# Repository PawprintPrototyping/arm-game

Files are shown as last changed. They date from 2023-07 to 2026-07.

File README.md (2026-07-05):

# opensauce23
Code, design files, etc for the coolest robot game at OpenSauce 2023 (and beyond!)

# MQTT System Architecture

The arm-game uses message passing via MQTT topics to drive each gameplay component.  Here's a state diagram showing how each topic drives the gameplay state:

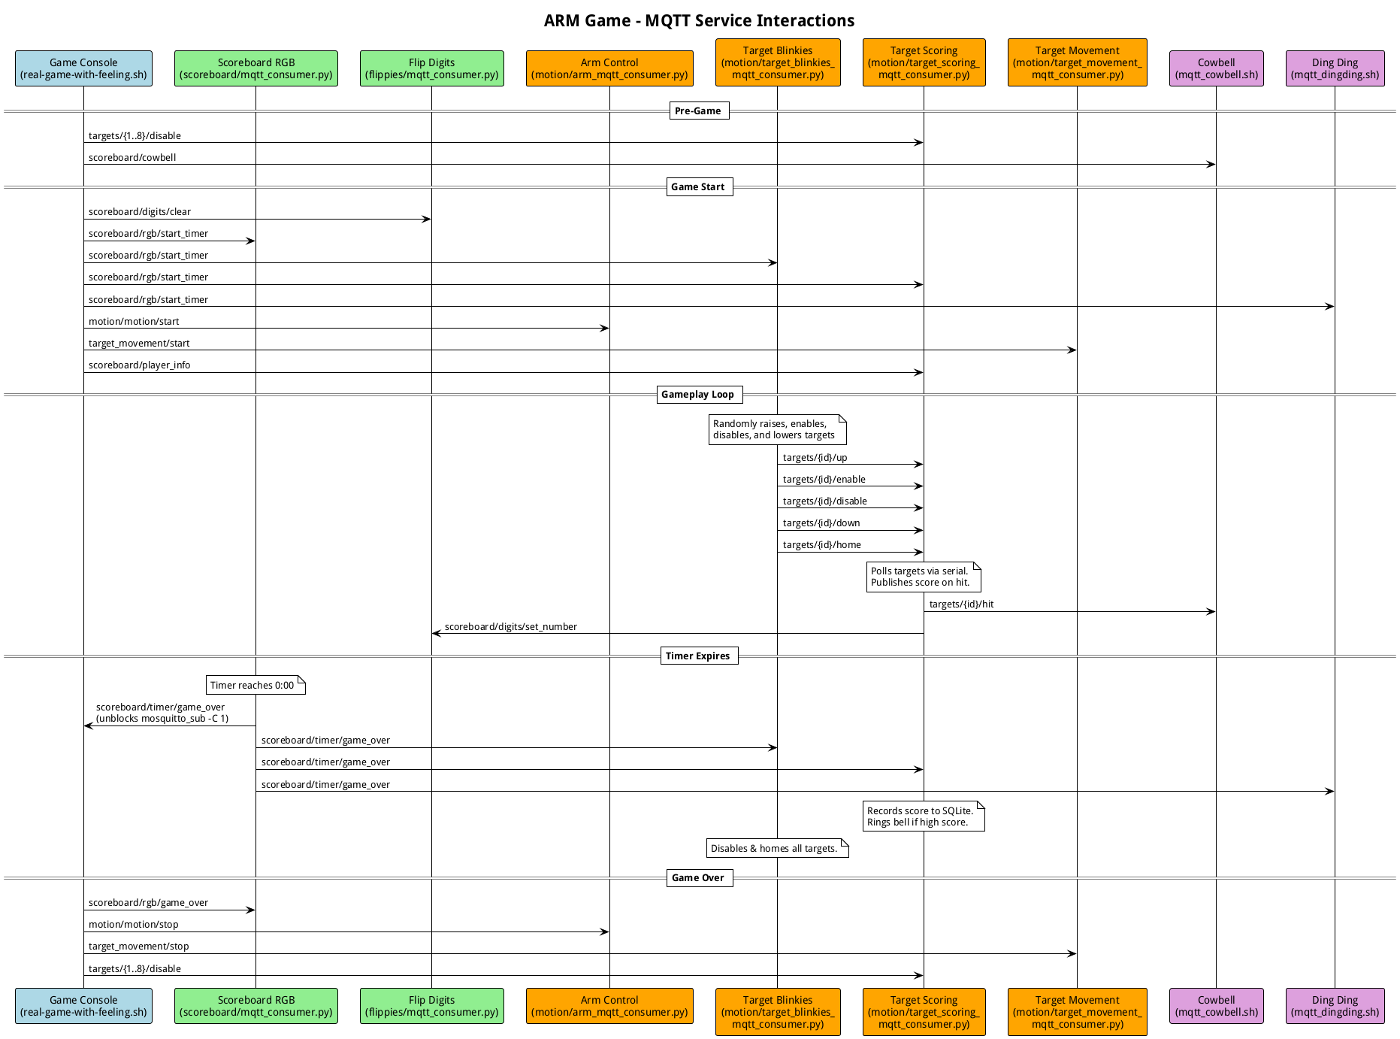
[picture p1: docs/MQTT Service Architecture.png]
MQTT Topic Architecture


Another overview of how each topic queue and component interacts:

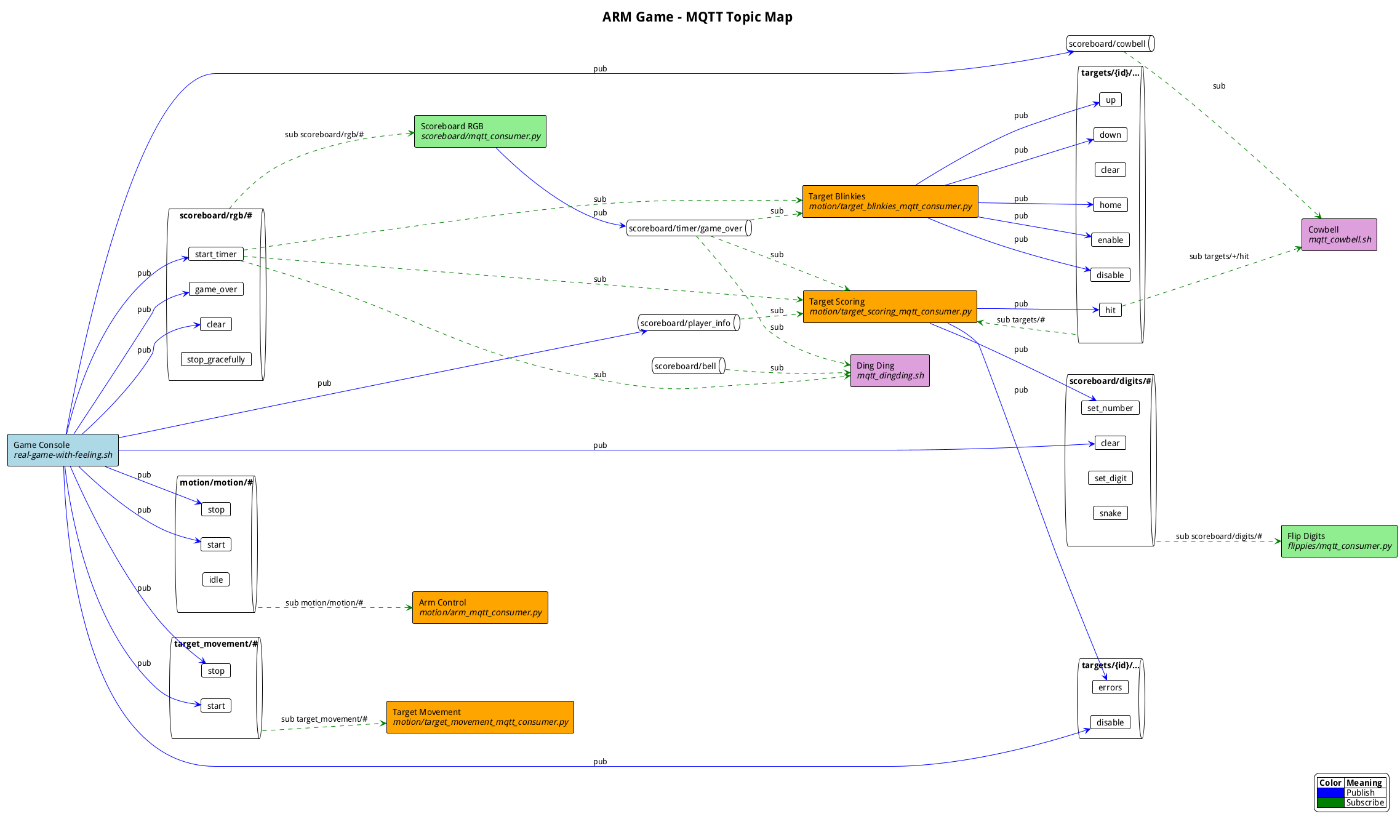
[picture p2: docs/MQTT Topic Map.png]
MQTT Topic Map


Detailed MQTT Topic API documentation can be found in [the docs folder](https://github.com/PawprintPrototyping/arm-game/tree/main/docs).

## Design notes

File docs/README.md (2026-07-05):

# MQTT API documentation

* [Flip Digits API](https://github.com/PawprintPrototyping/arm-game/tree/main/docs/flippies_api.md) - Flip digit scoreboard topics (/scoreboard/digits/...)
* [RGB Scoreboard API](https://github.com/PawprintPrototyping/arm-game/tree/main/docs/scoreboard_api.md) — RGB matrix display topics (/scoreboard/rgb/...)
* [Arm Motion API](https://github.com/PawprintPrototyping/arm-game/tree/main/docs/arm_motion_api.md) — robot arm control (/motion/motion/...)
* [Target Blinkies API](https://github.com/PawprintPrototyping/arm-game/tree/main/target_blinkies_api.md) — target lighty-uppy sequencer (subscribes to timer events, publishes target commands)
* [Target Movement API](https://github.com/PawprintPrototyping/arm-game/tree/main/docs/target_movement_api.md) — stepper motor platform (/target_movement/...)
* [Target Scoring API](https://github.com/PawprintPrototyping/arm-game/tree/main/docs/target_scoring_api.md) — hit detection, scoring, and high scores (/targets/{id}/...)

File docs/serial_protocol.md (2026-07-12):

# Serial protocol reference

Wire protocol for the target scoring bus (RS-485, multi-drop, baud 14400) between
[`TargetScoringSerial`](../motion/target_scoring_serial.py) and the target boards
([`target_controller/target_stepper`](../target_controller/target_stepper/src/main.cpp)). Boards
are addressed by id (0-15), discovered at startup.

Two protocols coexist on the bus during migration; discovery auto-detects which each board speaks.

## Legacy ASCII

| Command | Response |
|---|---|
| `poll {id}\n` | `{id} poll {enabled} {hit} {position}\n` |
| `enable {id}\n` | `{id} enable ok\n` |
| `disable {id}\n` | `{id} disable ok\n` |
| `clear {id}\n` | `{id} clear ok\n` |
| `home {id}\n` | `{id} home start\n` |
| `up {id}\n` | `{id} up start\n` |
| `down {id}\n` | `{id} down start\n` |

`enabled`/`hit` are `0`/`1`. `position` is `0` (unknown), `1` (home), `2` (up).

## Binary

Header byte:

```
 bit:   7   6 5 4 3   2 1 0
      +---+-------+-------+
      | R |  id   | opcode|
      +---+-------+-------+
```

`R` = 1 on a response frame (echoed back), 0 on a command. `id` is 0-15, `opcode` per the table below.

Command frame (3 bytes):

```
 byte:    0        1        2
      +------+--------+--------+
      | 0xAA | header |  crc8  |
      +------+--------+--------+
```

Response frame (4 bytes):

```
 byte:    0        1        2        3
      +------+--------+--------+--------+
      | 0xAA | header | status |  crc8  |
      +------+--------+--------+--------+
```

| Opcode | Command |
|---|---|
| 1 | poll |
| 2 | enable |
| 3 | disable |
| 4 | clear |
| 5 | home |
| 6 | up |
| 7 | down |

Poll status byte: `bit0=enabled bit1=hit bits2-3=position`. Other opcodes: `0x00=OK`.

CRC-8 is poly `0x07`, init `0x00`. A board that gets a bad CRC, or a frame for a different id,
stays silent — the host retries.

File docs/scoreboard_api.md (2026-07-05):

# MQTT API for RGB matrix scoreboard

All arguments are passed as a JSON-encoded payload.

## Subscribes to `scoreboard/rgb/#`

### `scoreboard/rgb/clear`

Clears the RGB matrix display.  No arguments.

### `scoreboard/rgb/start_timer`

Starts the game countdown timer on the display.  No arguments.

The timer counts down from a configurable duration (default: 1 minute).
When the timer expires, the scoreboard automatically transitions to the `GAME_OVER` state.

### `scoreboard/rgb/game_over`

Displays a game over screen on the RGB matrix.

**Optional**: `text (string)`: `"GAME OVER"` — custom message to display

**Optional**: `x (int)`: `12` — horizontal text position

**Optional**: `y (int)`: `25` — vertical text position

### `scoreboard/rgb/stop_gracefully`

Stops the scoreboard processing thread gracefully.  No arguments.

## Publishes

### `scoreboard/timer/game_over`

Published when the game over screen is displayed (either from timer expiry or an explicit `scoreboard/rgb/game_over` message).  Payload: `"GAME OVER"`.

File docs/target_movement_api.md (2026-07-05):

# MQTT API for target movement

Controls the side target platform stepper motor movement over serial to an Arduino with two stepper motor drivers and limit switches on each end.

See the corresponding Arduino sketch in [target_controller/target_stepper](https://github.com/PawprintPrototyping/arm-game/tree/main/target_controller/target_stepper).

Also pretty dead-nuts stupid simple.  The two internal states are `flail` and `stop`.

## Subscribes to `target_movement/#`

### `target_movement/start`

Starts the target platform movement (sends `flail` command to the stepper controller).  No arguments.

### `target_movement/stop`

Stops the target platform movement.  No arguments.

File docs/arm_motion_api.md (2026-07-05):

# MQTT API for robot arm motion control

All arguments are passed as a JSON-encoded payload.

Nothing fancy here.  It's pretty much either on or off.

## Subscribes to `/motion/motion/#`

### `/motion/motion/start`

Sets the robot arm to the `ACTIVE` state.  The arm will continuously move between random preset positions (`p1`–`p5`, `tease1`, `tease2`).  No arguments.

### `/motion/motion/stop`

Sets the robot arm to the `PARK` state.  The arm moves to its home position (`p1`) and then transitions to idle.  No arguments.

### `/motion/motion/idle`

Sets the robot arm to the `IDLE` state.  The arm stops moving immediately without returning to a home position.  No arguments.

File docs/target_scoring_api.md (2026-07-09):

# MQTT API for target scoring

Manages physical target hit detection, scoring, and high score tracking over serial.  Targets are addressed by numeric ID.

The `target_scoring_serial.py` service discovers connected targets at startup by probing every valid address (0-15) once and keeping the responders.  It then regularly polls that live set to check for hits.

Each target's poll outcomes are tracked in a sliding window.  If the recent error rate exceeds the configured threshold, the target is temporarily skipped by the polling loop and probed again every few seconds so it can be re-enabled automatically once it recovers.

All arguments are passed as a JSON-encoded payload.

## Subscribes

### `targets/{id}/enable`

Enables hit detection on the specified target.  No arguments.

### `targets/{id}/disable`

Disables hit detection on the specified target.  No arguments.

### `targets/{id}/clear`

Clears the hit state on the specified target.  No arguments.

### `targets/{id}/home`

Sends the specified target to its home position.  No arguments.

### `targets/{id}/up`

Raises the specified target.  No arguments.

### `targets/{id}/down`

Lowers the specified target.  No arguments.

### `scoreboard/rgb/start_timer`

Resets the current score to 0 for a new game.  No arguments.

### `scoreboard/timer/game_over`

Records the final score to the database (if a player name is set) and rings the bell if a high score was achieved.  Resets player info afterwards.  No arguments.

### `scoreboard/player_info`

Sets the current player's info for score recording.

**Required**: `name (string)` — player name

## Publishes

### `targets/{id}/hit`

Published when a target registers a hit.  Payload: `"hit {id}"`.

### `scoreboard/digits/set_number`

Published after each hit to update the flipdigit score display.  Payload: JSON `{"number": <score>}`.

Scoring: target 2 awards 75 points, all other targets award 69 points.

### `target/{id}/errors`

Published when a target poll response cannot be parsed.  Payload: JSON `{"target": <id>, "error_count": <count>}`.

### `targets/available`

Published (retained) after startup discovery with the list of target IDs that responded.  Payload: JSON `{"targets": [<id>, ...]}`.

### `target/{id}/health`

Published (retained) when a target transitions between healthy and unhealthy.  Payload: JSON snapshot of the target's sliding-window stats:

```json
{
  "target": 3,
  "healthy": false,
  "error_rate": 0.85,
  "error_count": 42,
  "poll_count": 118,
  "window_size": 20
}
```

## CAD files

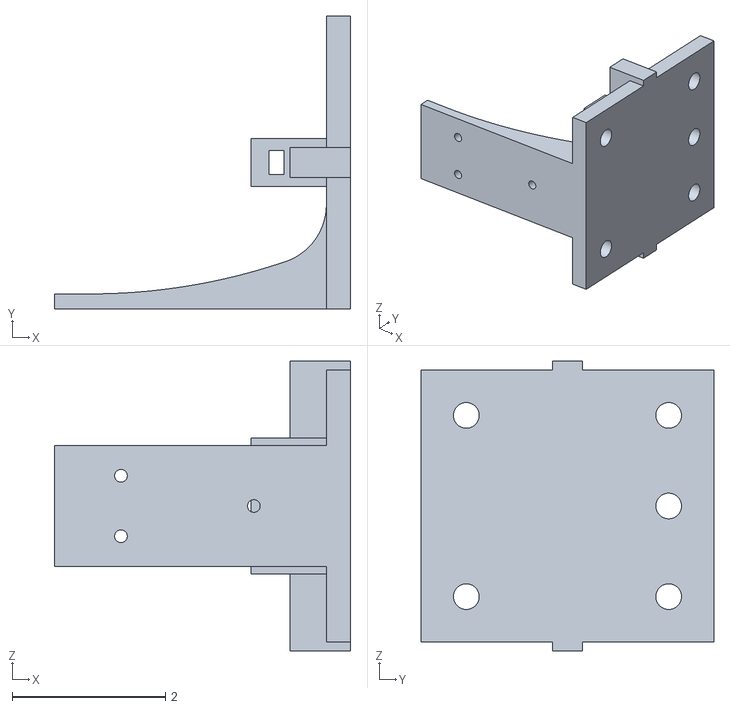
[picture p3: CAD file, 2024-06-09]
target_movement/Gantry CAD/ArmTargetGantryMain_v2.stl
3.86 x 3.82 x 3.78

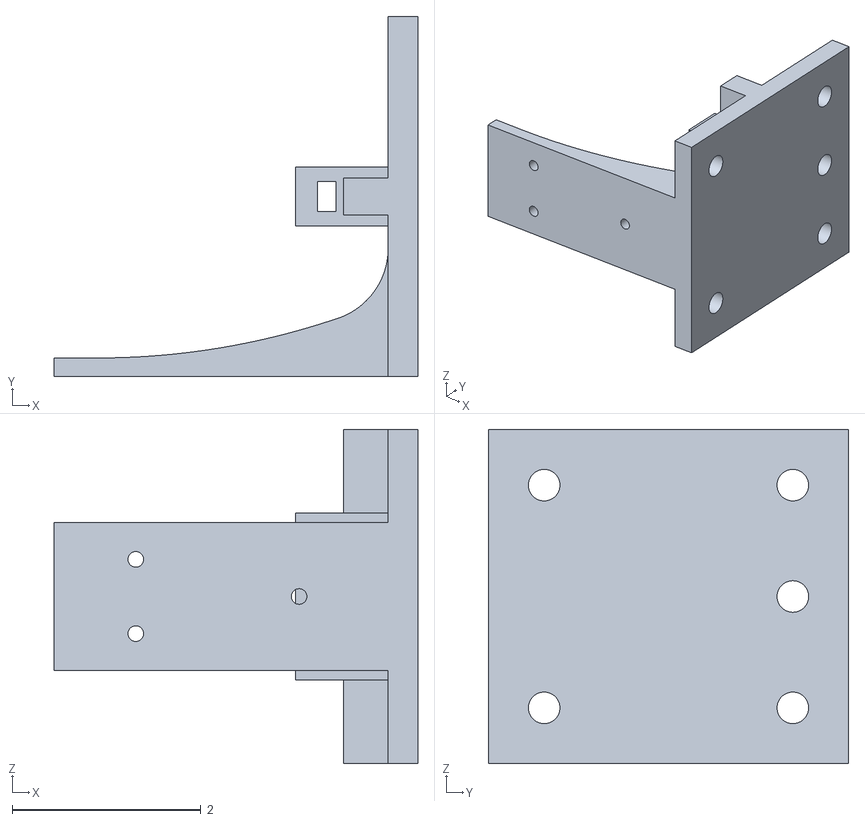
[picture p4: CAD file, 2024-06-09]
target_movement/Gantry CAD/ArmTargetGantryMain.stl
3.86 x 3.82 x 3.54

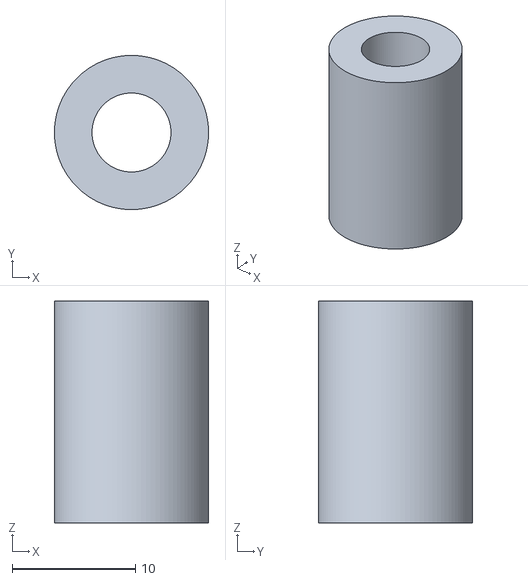
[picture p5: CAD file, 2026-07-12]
target_controller/CAD/spacer.stl
12.5 x 12.5 x 18.0

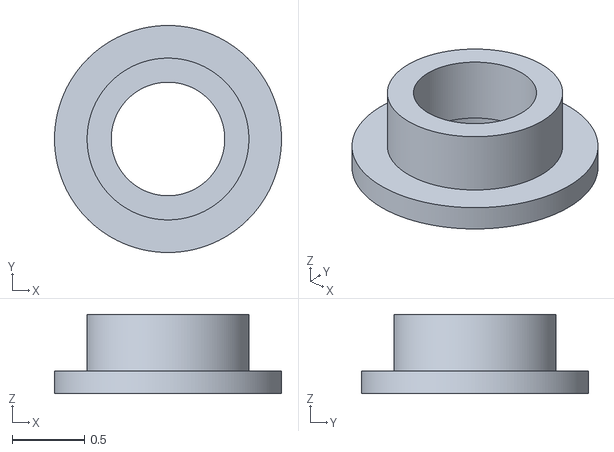
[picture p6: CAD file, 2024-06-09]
target_movement/Gantry CAD/ArmTargetGantryRollerHalf.stl
1.57 x 1.57 x 0.551

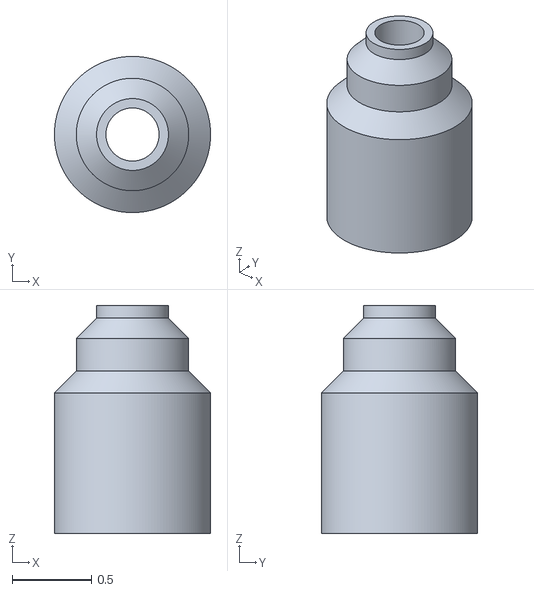
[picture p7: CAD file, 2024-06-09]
target_movement/Gantry CAD/ArmTargetGantryRollerStandoff.stl
0.984 x 0.984 x 1.44

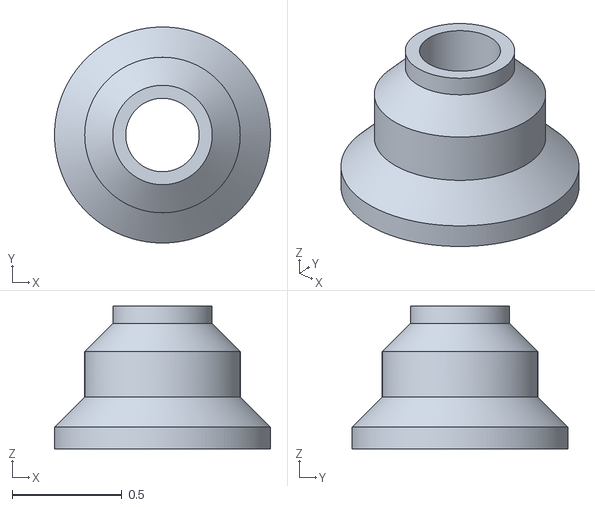
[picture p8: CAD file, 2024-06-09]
target_movement/Gantry CAD/ArmTargetGantryRollerStandoff_v2.stl
0.984 x 0.984 x 0.65

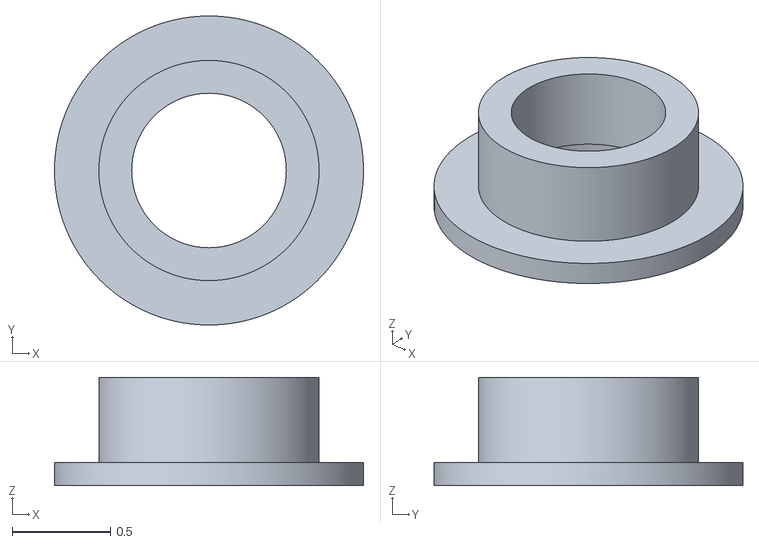
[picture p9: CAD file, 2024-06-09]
target_movement/Gantry CAD/ArmTargetGantryRollerHalf_v3.stl
1.57 x 1.57 x 0.551

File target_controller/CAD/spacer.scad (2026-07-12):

// Spacer to mount targets to side fumblers, robot, and flappy-doos

$fn = 100;

module spacer(id, od, length) {
    difference() {
        cylinder(h=length, r=od/2);
        cylinder(h=length, r=id/2);
    }
}

spacer(id=6.4, od=12.5, length=18);

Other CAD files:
target_movement/Gantry CAD/ArmTargetGantryRollerHalf_v2.stl

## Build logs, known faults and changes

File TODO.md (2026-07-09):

# TODO

## Robot communications handling

* Signals to handle:
  - [ ] `ash: Arm power is OFF`
  - [ ] `[ash: Caught SIGABRT]`
* [ ] Add polling for current position
* [ ] Compare to commanded position
* [ ] Tight loop handling to service other sensors and timers

## Ops

- [ ] Ops dashboard
- [ ] Write an ansible playbook to configure services on a fresh pi

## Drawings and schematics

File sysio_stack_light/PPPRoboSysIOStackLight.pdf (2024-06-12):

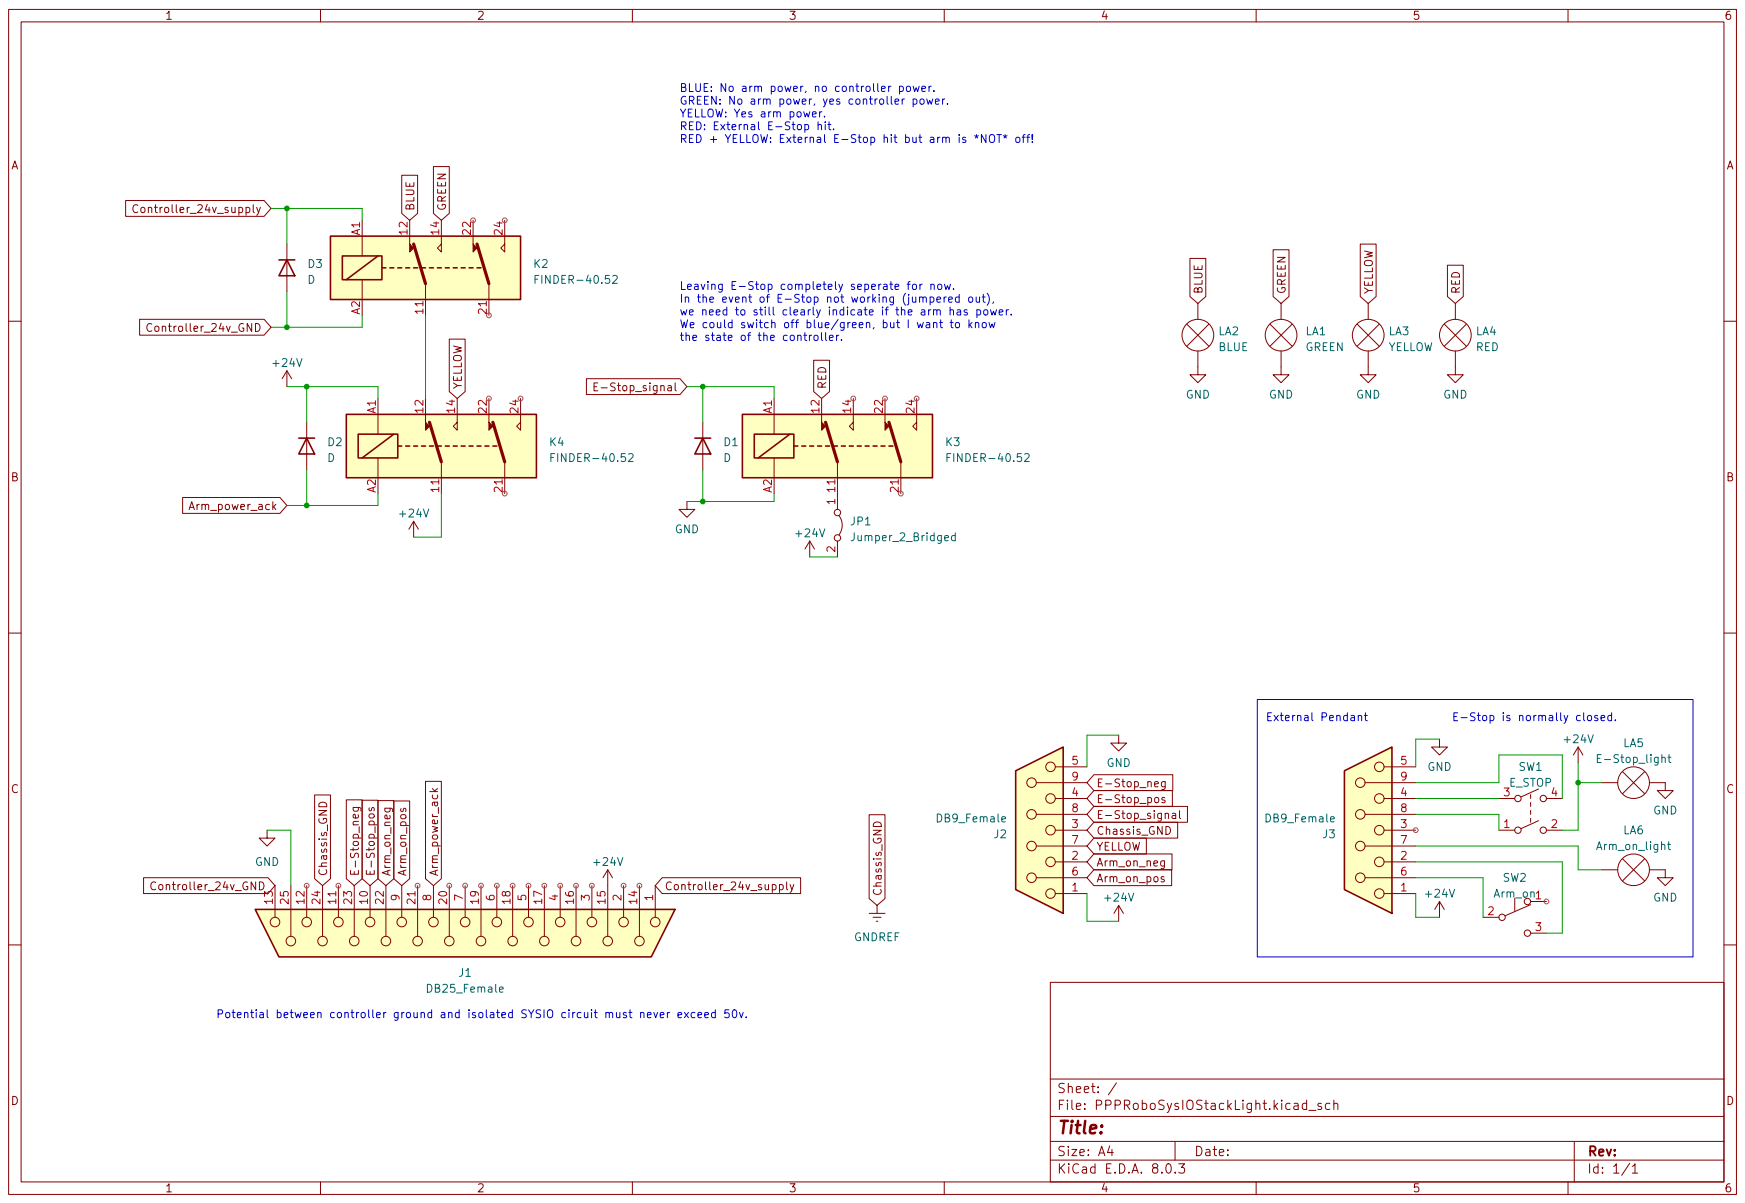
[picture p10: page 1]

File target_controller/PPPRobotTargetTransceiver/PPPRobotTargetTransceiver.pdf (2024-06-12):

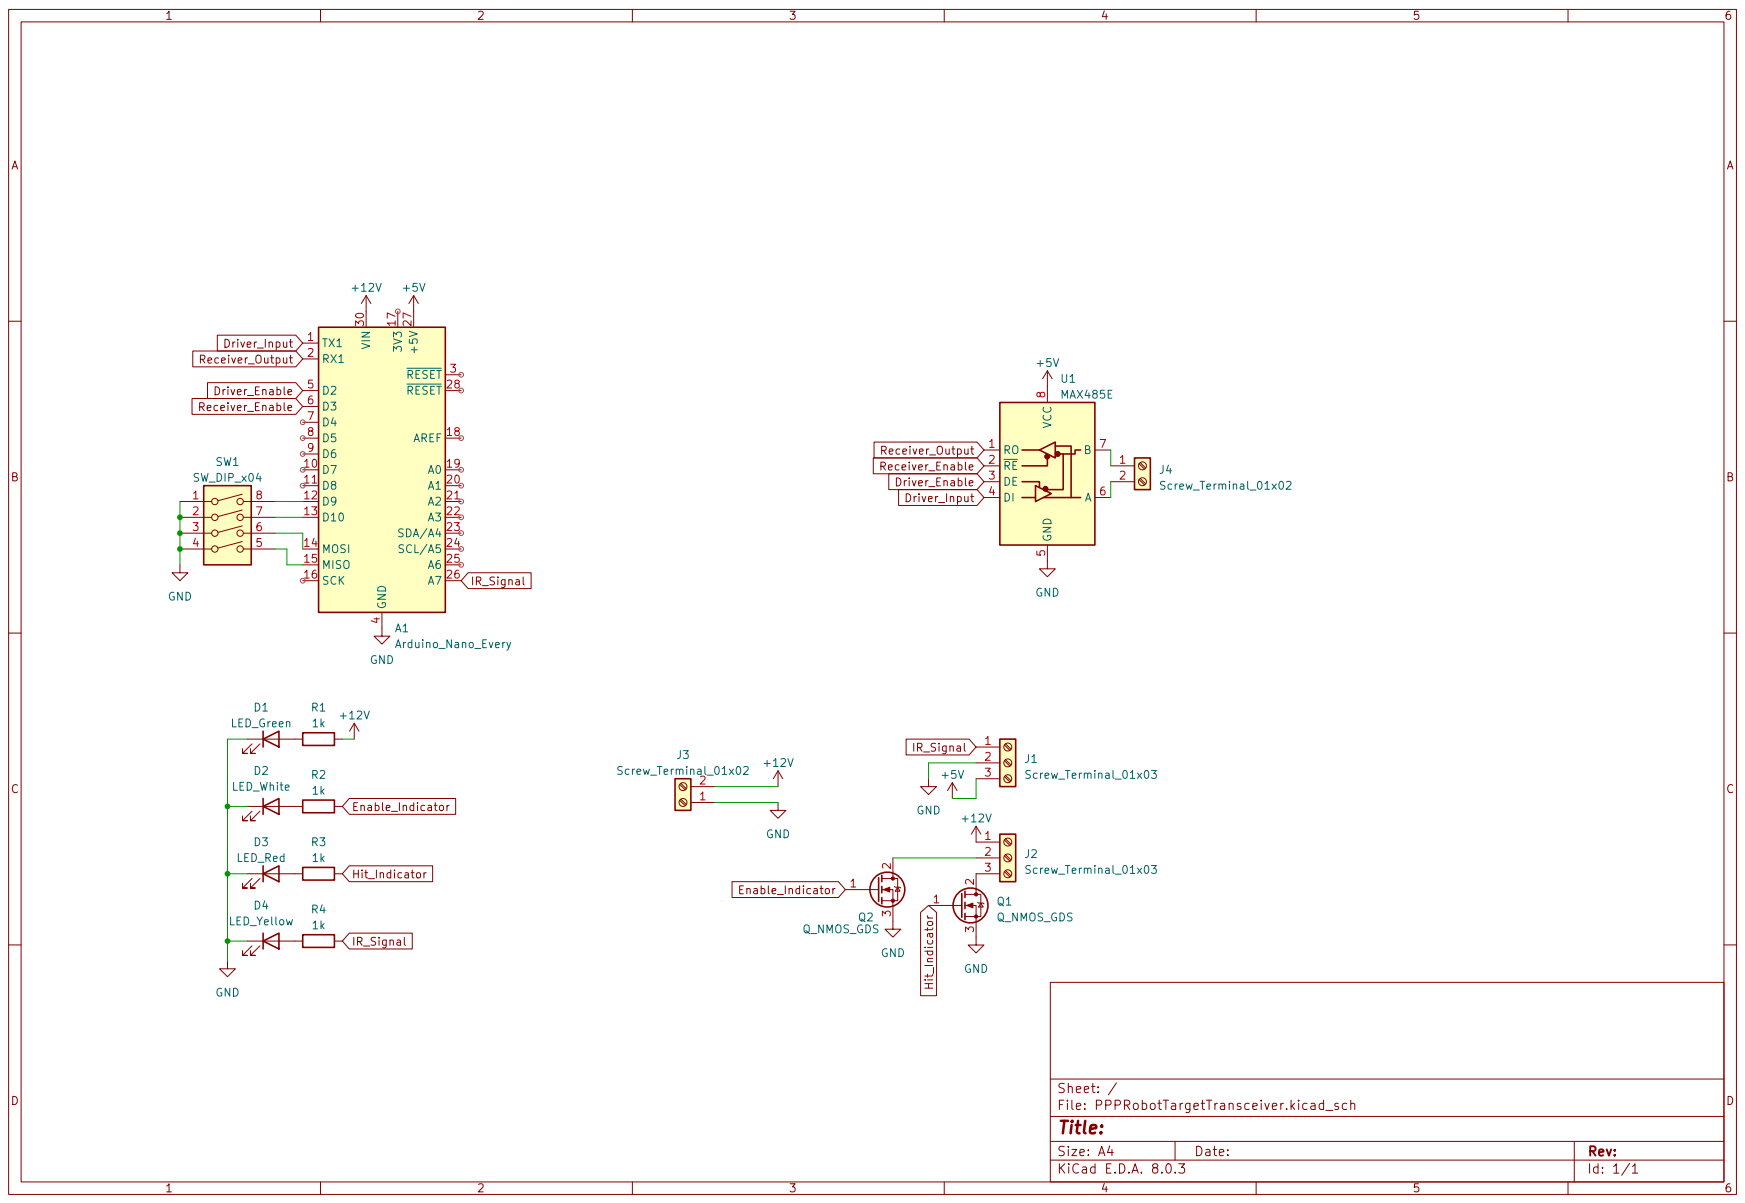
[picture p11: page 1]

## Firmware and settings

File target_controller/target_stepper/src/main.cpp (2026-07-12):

#include <Arduino.h>
#include <CircularBuffer.hpp>
#include <TimerOne.h>
#include <StepperState.h>

// NOTE ON FLASHING: The Nano only has one UART, so the serial lines connected to USB are also tied to the MAX485 transceiver.
// There's a 2 second delay in setup() that *should* allow flashing, but you may need to remove the arduino from the socket to flash it.
// This also means that the arduino probably won't respond to serial commands sent via the USB adapter.
// The MAX485 is also driving the pin and it's stronger than the USB adapter.
// This ALSO means that, if you flash the arduino via USB, the flashing data might get blasted across the MAX485.

/*
General weaselbrained theory of operation:
We'll receive a signal from the IR receiver when it's hit by the blaster (or other IR sources).
That signal is (for our purposes) 7 bytes long. Each bit is bitDuration microseconds long.
So, let's just set a timer every bitDuration, call an interrupt, and slap the current state of the receive pin into a 56 bool circular receiveBuffer.
Compare the receiveBuffer with the blasterPattern during every timer tick. If they match, we've been hit.
When hit, we'll set lastHit to the current millis().
The main loop will wait for polls and respond with a hit if lastHit is within iframeDuration of the current millis() at polling.
There'll be a few millisecond window every ~49 days of uptime where we might miss a hit due to milis() rolling over. Preeeety sure that won't be a problem though.

It was easier to use the timer to handle the hit indicator output and let the main loop do serial stuff, so that's what I did.

Regarding the MAX485 transceiver, we need to enable the driver for the duration of any transmissions.
Since we can't easily tell when the serial transmission is finished (AFAICT), we'll just use a set max485DriverEnableDuration and cross our fingers.
*/

const int stepperLimitPin = A2;
const int hitIndicatorPin = 5;
const int enableIndicatorPin = 4;
const int stepperPwmPin = 6;
const int stepperDirPin = 7;
const int max485DriverEnablePin = 2;
const int max485ReceiverEnablePin = 3;
const int idPin0 = 8;
const int idPin1 = 9;
const int idPin2 = 10;
const int idPin3 = MOSI;
const int irDataPin = A0;
const int bitDuration = 500; // microseconds.
const int iframeDuration = 1000; // milliseconds.

/* amount of time assumed for a message to to go out of the serial TX buffer.  See Weasel comment above on line 33. */
const int max485DriverEnableDuration = 20; // milliseconds. Increase if decreasing baudrate.
const bool blasterPattern[56] = {
  0,0,0,0,
  0,0,0,0,
  0,0,0,1,
  0,0,0,1,
  0,1,1,1,
  0,0,0,1,
  0,1,1,1,
  0,1,1,1,
  0,0,0,1,
  0,1,1,1,
  0,0,0,1,
  0,0,0,1,
  1,1,1,1,
  1,1,1,1
};
const int blasterPatternLen = 56;
CircularBuffer<bool, 56> receiveBuffer;
StepperState* stepperState;
volatile unsigned long lastHit = 0;
unsigned int id = 0;
volatile int enabled = 0;
volatile int hit = 0;
volatile bool hitStat = false;
volatile long lastTransmitTimeMillis = -1;

// Compact binary framing (see docs/serial_protocol.md). Coexists with the legacy ASCII
// commands below so boards can be reflashed one at a time: the sync byte can't be
// confused with the first character of any ASCII command (those all start with a
// lowercase letter).
const uint8_t syncByte = 0xAA;
const uint8_t responseFlag = 0x80;
const uint8_t opcodePoll = 1;
const uint8_t opcodeEnable = 2;
const uint8_t opcodeDisable = 3;
const uint8_t opcodeClear = 4;
const uint8_t opcodeHome = 5;
const uint8_t opcodeUp = 6;
const uint8_t opcodeDown = 7;

bool binaryFrameActive = false;
int binaryBytesRead = 0;
uint8_t binaryFrameBuf[2]; // header, crc

String inputString;

String pollCmdStr;
String enableCmdStr;
String disableCmdStr;
String clearCmdStr;
String homeCmdStr;
String hideCmdStr;
String showCmdStr;

void setMax485Timestamp() {
  lastTransmitTimeMillis = millis();
}

void enableMax485Driver() {
  digitalWrite(max485DriverEnablePin, HIGH);
  digitalWrite(max485ReceiverEnablePin, HIGH); // Disable receiver when transmitting.
  setMax485Timestamp();
}

void disableMax485Driver() {
  digitalWrite(max485DriverEnablePin, LOW);
  digitalWrite(max485ReceiverEnablePin, LOW); // We're done transmitting, reenable the receiver.
}

bool checkHit() {
  // Don't try to compare until we have a full buffer to work with.
  if (receiveBuffer.isFull() == false) {
    return false;
  }
  for (int i = 0; i < blasterPatternLen; i++) {
    if (receiveBuffer[i] != blasterPattern[i]) {
      return false;
    }
  }
  // Didn't bail out? Everything matches - we're hit!
  return true;
}

void timerHandler() {
  receiveBuffer.push(digitalRead(irDataPin));
  if (hit == 1 && lastHit + iframeDuration < millis()) {
    digitalWrite(hitIndicatorPin, LOW);
    hit = 0;
  }
  if (checkHit()) {
    lastHit = millis();
    if (enabled == 1 && hit == 0) {
      digitalWrite(hitIndicatorPin, HIGH);
      hit = 1;
      hitStat = true;
      stepperState->setPosition(StepperState::Position::HOME);
    }
  }
}

// Expected usage: "poll <int id>"
void cmdPoll() {
  //String enabledMsg = "off";
  String enabledMsg = "0";
  if (enabled) {
    //enabledMsg = "on";
    enabledMsg = "1";
  }
  //String hitMsg = "unhit"; // Is there a better word for this?...
  String hitMsg = "0";
  if (hitStat) {
    //hitMsg = "hit";
    hitMsg = "1";
  }

  String positionMsg;
  switch (stepperState->getPosition()) {
    case StepperState::HOME:
      positionMsg = "1";
      break;
    case StepperState::UP:
      positionMsg = "2";
      break;
    default:
      positionMsg = "0";
      break;
  }
  //String respStr = String(id) + " poll " + enabledMsg + " " + hitMsg + " " + lastHit + " " + millis(); // mmm yess, very efficiency
  String respStr = String(id) + " poll " + enabledMsg + " " + hitMsg + " " + positionMsg;
  enableMax485Driver();
  Serial.println(respStr);
}

void cmdClear() {
  hitStat = false;
  String respStr = String(id) + " clear ok";
  enableMax485Driver();
  Serial.println(respStr);
}

void cmdEnable() {
  enabled = 1;
  digitalWrite(enableIndicatorPin, HIGH);
  String respStr = String(id) + " enable ok";
  enableMax485Driver();
  Serial.println(respStr);
}

void cmdDisable() {
  enabled = 0;
  digitalWrite(enableIndicatorPin, LOW);
  String respStr = String(id) + " disable ok";
  enableMax485Driver();
  Serial.println(respStr);
}

void cmdHome() {
  stepperState->findHome();
  String respStr = String(id) + " home start";
  enableMax485Driver();
  Serial.println(respStr);
}
void cmdHide() {
  stepperState->setPosition(StepperState::Position::HOME);
  String respStr = String(id) + " down start";
  enableMax485Driver();
  Serial.println(respStr);
}

void cmdShow() {
  stepperState->setPosition(StepperState::Position::UP);
  String respStr = String(id) + " up start";
  enableMax485Driver();
  Serial.println(respStr);
}

// Must match TargetScoringSerial._crc8() in motion/target_scoring_serial.py exactly:
// poly 0x07, init 0x00.
uint8_t crc8(const uint8_t* data, size_t len) {
  uint8_t crc = 0;
  for (size_t i = 0; i < len; i++) {
    crc ^= data[i];
    for (int b = 0; b < 8; b++) {
      crc = (crc & 0x80) ? ((crc << 1) ^ 0x07) : (crc << 1);
    }
  }
  return crc;
}

void sendBinaryResponse(uint8_t opcode, uint8_t status) {
  uint8_t frame[4];
  frame[0] = syncByte;
  frame[1] = responseFlag | ((id & 0x0F) << 3) | (opcode & 0x07);
  frame[2] = status;
  frame[3] = crc8(&frame[1], 2);
  enableMax485Driver();
  Serial.write(frame, 4);
}

// Dispatches a binary command frame addressed to our id. Silently ignores anything
// addressed to another board or with an unrecognized opcode - the host will time out
// and retry rather than get a NAK.
void handleBinaryFrame(uint8_t header) {
  uint8_t reqId = (header >> 3) & 0x0F;
  uint8_t opcode = header & 0x07;
  if (reqId != id) {
    return;
  }

  switch (opcode) {
    case opcodePoll: {
      uint8_t status = 0;
      if (enabled) status |= 0x01;
      if (hitStat) status |= 0x02;
      uint8_t posBits;
      switch (stepperState->getPosition()) {
        case StepperState::HOME: posBits = 1; break;
        case StepperState::UP: posBits = 2; break;
        default: posBits = 0; break;
      }
      status |= (posBits & 0x03) << 2;
      sendBinaryResponse(opcodePoll, status);
      break;
    }
    case opcodeEnable:
      enabled = 1;
      digitalWrite(enableIndicatorPin, HIGH);
      sendBinaryResponse(opcodeEnable, 0x00);
      break;
    case opcodeDisable:
      enabled = 0;
      digitalWrite(enableIndicatorPin, LOW);
      sendBinaryResponse(opcodeDisable, 0x00);
      break;
    case opcodeClear:
      hitStat = false;
      sendBinaryResponse(opcodeClear, 0x00);
      break;
    case opcodeHome:
      stepperState->findHome();
      sendBinaryResponse(opcodeHome, 0x00);
      break;
    case opcodeUp:
      stepperState->setPosition(StepperState::Position::UP);
      sendBinaryResponse(opcodeUp, 0x00);
      break;
    case opcodeDown:
      stepperState->setPosition(StepperState::Position::HOME);
      sendBinaryResponse(opcodeDown, 0x00);
      break;
    default:
      break;
  }
}

void setup() {
  stepperState = new StepperState(stepperPwmPin, stepperDirPin, stepperLimitPin);
  pinMode(irDataPin, INPUT);
  pinMode(stepperPwmPin, OUTPUT);
  pinMode(stepperDirPin, OUTPUT);
  pinMode(hitIndicatorPin, OUTPUT);
  pinMode(enableIndicatorPin, OUTPUT);
  pinMode(max485DriverEnablePin, OUTPUT);
  pinMode(max485ReceiverEnablePin, OUTPUT);
  pinMode(idPin0, INPUT_PULLUP);
  pinMode(idPin1, INPUT_PULLUP);
  pinMode(idPin2, INPUT_PULLUP);
  pinMode(idPin3, INPUT_PULLUP);
  pinMode(stepperLimitPin, INPUT_PULLUP);

  // The MAX485 transceiver can make it impossible to flash the arduino without removing it from the circuit.
  // Let's turn the transceiver off (RE is active low) and wait for two seconds to give us a chance to flash.
  digitalWrite(max485ReceiverEnablePin, HIGH);
  delay(2000);
  // Otherweise, we want the receiver to be on unless we're transmitting.
  digitalWrite(max485ReceiverEnablePin, LOW);

  Serial.begin(14400);
  while (!Serial);

  // The ID selection pins are INPUT_PULLUP, so they're HIGH (00000001) when off and LOW (00000000) when on.
  // This makes it a bit funky to bit-shift, so I'm just XORing with 00000001 to flip it before shifting and ORing.
  id = (digitalRead(idPin0) ^ 1);
  id = id | (digitalRead(idPin1) ^ 1) << 1;
  id = id | (digitalRead(idPin2) ^ 1) << 2;
  id = id | (digitalRead(idPin3) ^ 1) << 3;
  
  // Why not just do `String str = "stuff " + id`?
  // Because that causes the beginning of the string to get munched.
  // I'm sure there's a clear and logical reason why, but fuck if I know what it is.
  pollCmdStr = "poll ";
  pollCmdStr += id;
  //Serial.println(pollCmdStr);
  enableCmdStr = "enable ";
  enableCmdStr += id;
  //Serial.println(enableCmdStr);
  disableCmdStr = "disable ";
  disableCmdStr += id;
  //Serial.println(disableCmdStr);
  clearCmdStr = "clear ";
  clearCmdStr += id;
  //Serial.println(clearCmdStr);
  homeCmdStr = "home ";
  homeCmdStr += id;
  hideCmdStr += "down ";
  hideCmdStr += id;
  showCmdStr += "up ";
  showCmdStr += id;
  
  Timer1.initialize(bitDuration);
  Timer1.attachInterrupt(timerHandler);
  
  //enableMax485Driver();
  //Serial.println(String(id) + " henlo");
  disableMax485Driver(); // set to receive
}

void loop() {
  bool wasMoving = stepperState->isMoving();
  stepperState->move();
  bool isMoving = stepperState->isMoving();
  // Do not allow timer interrupts when we are moving to keep the stepper consistent.
  if (!wasMoving && isMoving) {
    Timer1.detachInterrupt();
  }
  if (wasMoving && !isMoving) {
    Timer1.attachInterrupt(timerHandler);
  }

  // Set transmitter to receive after max485DriverEnableDuration has passed since transmit.
  if (lastTransmitTimeMillis >= 0) {
    if ((millis() - lastTransmitTimeMillis) >= max485DriverEnableDuration) {
      disableMax485Driver();
      lastTransmitTimeMillis = -1;
    } else {
      return;
    }
  }

  if (!Serial.available()) return;
  // Only read one character per loop to not disrupt moving the targets for too long.
  int c = Serial.read();

  if (binaryFrameActive) {
    binaryFrameBuf[binaryBytesRead++] = (uint8_t) c;
    if (binaryBytesRead >= 2) {
      binaryFrameActive = false;
      uint8_t header = binaryFrameBuf[0];
      uint8_t crc = binaryFrameBuf[1];
      if (crc8(&header, 1) == crc) {
        handleBinaryFrame(header);
      }
    }
    return;
  }

  // A sync byte only starts a binary frame at a command boundary - mid-ASCII-command
  // stray bytes are just noise absorbed into inputString like any other bad input.
  if (!binaryFrameActive && (uint8_t) c == syncByte) {
    binaryFrameActive = true;
    binaryBytesRead = 0;
    return;
  }

  if (c != '\n' && c > 0) {
    inputString += (char) c;
    return;
  }

  inputString.trim();
  if (inputString == pollCmdStr) {
    cmdPoll();
  } else if (inputString == clearCmdStr) {
    cmdClear();
  } else if (inputString == enableCmdStr) {
    cmdEnable();
  } else if (inputString == disableCmdStr) {
    cmdDisable();
  } else if(inputString == homeCmdStr) {
    cmdHome();
  }else if(inputString == hideCmdStr) {
    cmdHide();
  } else if(inputString == showCmdStr) {
    cmdShow();
  }// else {
  //  Serial.print("Fucko boingo: ");
  //  Serial.println(inputString);
  //}
  inputString = "";
}

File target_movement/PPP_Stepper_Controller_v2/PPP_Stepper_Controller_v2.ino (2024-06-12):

#include <TimerOne.h>
#include <TimerThree.h>

static int aPulsePin = 7;
static int aDirectionPin = 6;
static int aEnablePin = 5;
static int aLimitTopPin = 18;
static int aLimitBottomPin = 19;
static int bLimitTopPin = 20;
static int bLimitBottomPin = 21;
static int bPulsePin = 4;
static int bDirectionPin = 3;
static int bEnablePin = 2;
static int calPulseDelay = 500; // microseconds.
static long calBufferPulses = 500; // Pulses of buffer to avoid at each end.
static long calSmidgePulses = 32; // Pulses to scootch off of (or in to)- the endstop during initial startup
static long minDualTravelPulses = 0;
static long bufferedDualTravelPulses = 0;

static long pulsesPerMeter = 8000;

long aCalPulses = 0;
long bCalPulses = 0;

bool flail = false;

volatile bool aLimitTopState = HIGH;
volatile bool aLimitBottomState = HIGH;
volatile bool bLimitTopState = HIGH;
volatile bool bLimitBottomState = HIGH;
volatile bool calDone = false;
volatile bool limitOverrun = false;

void fail(String message) {
  Serial.println("Entered fail state: " + message);
  while (1) {
    digitalWrite(LED_BUILTIN, HIGH);
    delay(500);
    digitalWrite(LED_BUILTIN, LOW);
    delay(500);
  }
}

// Should be executed when any limit switch interrupt is triggered.
void limitInterruptHandler() {
  aLimitTopState = digitalRead(aLimitTopPin);
  aLimitBottomState = digitalRead(aLimitBottomPin);
  bLimitTopState = digitalRead(bLimitTopPin);
  bLimitBottomState = digitalRead(bLimitBottomPin);
  // If a limit switch it hit after the calibration sequence, something has gone very wrong.
  // We need to stop movement and bail to prevent the steppers from blasting past the end stops.
  if (calDone) {
    if (aLimitTopState || aLimitBottomState || bLimitTopState || bLimitBottomState) {
      Timer1.stop();
      Timer3.stop();
      // We can't call fail() normally here, since we're inside an interrupt.
      limitOverrun = true;
    }
  }
}

// There is absolutely a better way of doing this but I'm lazy and dum.
bool checkALimitTop() {
  return(aLimitTopState);
}

bool checkALimitBottom() {
  return(aLimitBottomState);
}

bool checkBLimitTop() {
  return(bLimitTopState);
}

bool checkBLimitBottom() {
  return(bLimitBottomState);
}

void aPulse(int pulseDelay, bool pulseDirection) {
  digitalWrite(aDirectionPin, pulseDirection);
  digitalWrite(aEnablePin,HIGH);
  digitalWrite(aPulsePin,HIGH);
  delayMicroseconds(pulseDelay);
  digitalWrite(aPulsePin,LOW);
  delayMicroseconds(pulseDelay);
}

void aPulsePos(int pulseDelay) {
  aPulse(pulseDelay, true);
}

void aPulseNeg(int pulseDelay) {
  aPulse(pulseDelay, false);
}

void bPulse(int pulseDelay, bool pulseDirection) {
  digitalWrite(bDirectionPin, pulseDirection);
  digitalWrite(bEnablePin,HIGH);
  digitalWrite(bPulsePin,HIGH);
  delayMicroseconds(pulseDelay);
  digitalWrite(bPulsePin,LOW);
  delayMicroseconds(pulseDelay);
}

void bPulsePos(int pulseDelay) {
  bPulse(pulseDelay, true);
}

void bPulseNeg(int pulseDelay) {
  bPulse(pulseDelay, false);
}


void setup() {
  Serial.begin(9600);
  Serial.println("Henlo! Running startup cal...");
  pinMode(LED_BUILTIN, OUTPUT);
  pinMode(aPulsePin, OUTPUT);
  pinMode(aDirectionPin, OUTPUT);
  pinMode(aEnablePin, OUTPUT);
  pinMode(aLimitTopPin, INPUT_PULLUP);
  pinMode(aLimitBottomPin, INPUT_PULLUP);
  pinMode(bPulsePin, OUTPUT);
  pinMode(bDirectionPin, OUTPUT);
  pinMode(bEnablePin, OUTPUT);
  pinMode(bLimitTopPin, INPUT_PULLUP);
  pinMode(bLimitBottomPin, INPUT_PULLUP);

  // Prime the limit switch pin states.
  limitInterruptHandler();

  attachInterrupt(digitalPinToInterrupt(aLimitTopPin), limitInterruptHandler, CHANGE);
  attachInterrupt(digitalPinToInterrupt(aLimitBottomPin), limitInterruptHandler, CHANGE);
  attachInterrupt(digitalPinToInterrupt(bLimitTopPin), limitInterruptHandler, CHANGE);
  attachInterrupt(digitalPinToInterrupt(bLimitBottomPin), limitInterruptHandler, CHANGE);

  Timer1.initialize(1000000);
  Timer3.initialize(1000000);

  int i = 0;
  bool done = false;

  // Move the gantrys away from endstops a smidge before cal.
  if (checkALimitTop() || checkALimitBottom()) {
    Serial.println("Target A started at limit.");
    for (i=0;i<calSmidgePulses;i++) {
      aPulsePos(calPulseDelay);
    }
    if (checkALimitTop() || checkALimitBottom()) { // Still on the switch? Might have gone the wrong direction.
      Serial.println("Target A is still at limit. Trying opposite direction.");
      for (i=0;i<calSmidgePulses;i++) {
        aPulseNeg(calPulseDelay);
      }
      if (checkALimitTop() || checkALimitBottom()) {
        fail("Target A is stuck at a limit. Make sure the switch is wired up using the normally closed contacts.");
      }
    }
  }

  // Move the gantrys away from endstops a smidge before cal.
  if (checkBLimitTop() || checkBLimitBottom()) {
    Serial.println("Target B started at limit.");
    for (i=0;i<calSmidgePulses;i++) {
      bPulsePos(calPulseDelay);
    }
    if (checkBLimitTop() || checkBLimitBottom()) { // Still on the switch? Might have gone the wrong direction.
      Serial.println("Target B is still at limit. Trying opposite direction.");
      for (i=0;i<calSmidgePulses;i++) {
        bPulseNeg(calPulseDelay);
      }
      if (checkBLimitTop() || checkBLimitBottom()) {
        fail("Target B is stuck at a limit. Make sure the switch is wired up using the normally closed contacts.");
      }
    }
  }
  
  //// Check for any limit switch wiring faults.
  //if (checkALimitTop() || checkALimitBottom()) {
  //  fail("Target A is stuck at a limit. Make sure the switch is wired up using the normally closed contacts.");
  //}
  //if (checkBLimitTop() || checkBLimitBottom()) {
  //  fail("Target B is stuck at a limit. Make sure the switch is wired up using the normally closed contacts.");
  //}


  // Move the target to the top limit switch so we know where we are.
  while (done == false) {
    if (checkALimitBottom()) {
      fail("Target A traveled in the wrong direction. Its coils are probably wired in reverse.");
    } else if (checkALimitTop()) {
      done = true;
    } else {
      aPulsePos(calPulseDelay);
    }
  }
  // Move the target to the bottom limit switch and count pulses to determine max travel.
  i = 0;
  done = false;
  while (done == false) {
    if (checkALimitBottom()) {
      done = true;
    } else {
      i++;
      aPulseNeg(calPulseDelay);
    }
  }
  aCalPulses = i;
  Serial.println(aCalPulses);
  if (aCalPulses <= calBufferPulses * 2) {
    fail("Total travel pulses for target A are lower than the buffers.");
  }
  // Back away from the limit switch.
  for (i=0;i<calBufferPulses;i++) {
    aPulsePos(calPulseDelay);
  }
  delay(500); // Hacky way of preventing the limit overrun detection from firing as we're finishing the cal.
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

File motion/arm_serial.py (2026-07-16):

import structlog
import random
import time

from serial_base import SerialBase

PROMPT_TEXT="opensauce"

class ArmSerial(SerialBase):
    logger = structlog.get_logger()
    STARTUP_SCRIPT = b"""speed 100
stance fuf
"""
    ROBOT_LOCATIONS = ["p1", "p2", "p3", "p4", "p5", "tease1", "tease2"]

    IDLE = "idle"
    PARK = "park"
    ACTIVE = "active"
    ESTOP = "estop"

    def __init__(self, *args, **kwargs):
        ArmSerial.logger.debug("Opening robot serial", args=args, kwargs=kwargs)
        super().__init__(*args, **kwargs)
        self.state = ArmSerial.IDLE
        self.location = None

    def setup(self):
        self.assert_ash_prompt()
        self.write(ArmSerial.STARTUP_SCRIPT)

    def get_random_location(self):
        new_location = self.location
        while self.location == new_location:
            new_location = random.choice(ArmSerial.ROBOT_LOCATIONS)
        self.location = new_location
        return new_location

    def run(self):
        while not self.stop:
            match self.state:
                case ArmSerial.ACTIVE:
                    self.finish(self.get_random_location())
                case ArmSerial.PARK:
                    # Move to the final resting position and transition state to idle
                    self.finish("p1")
                    self.state = ArmSerial.IDLE
            time.sleep(0.05)

    def assert_ash_prompt(self):
        self.ser.write(b'\n')
        prompt = self.ser.readline()
        ArmSerial.logger.info("assert_ash_prompt readline()", prompt=prompt)
        prompt += self.ser.read(len(PROMPT_TEXT)+2)
        ArmSerial.logger.info("assert_ash_prompt readline()", prompt=prompt)
        if prompt.decode('latin1') != f"\r\n{PROMPT_TEXT}> ":
            print(f"Not in an ash!  (got '{prompt}' but expected '{PROMPT_TEXT}> ')")
            assert False
        assert True

    def poll_position(self):
        # Check to see if the missile knows where it is
        # (commanded position matches current position)
        pass

    def check_estop(self, message):
        if b'Arm power is OFF\r\n' in message:
            ArmSerial.logger.error("Unable to move, Arm power is OFF!")
            ArmSerial.logger.info("Setting state to ESTOP")
            self.state = ArmSerial.ESTOP
            # At this point, these extra signal messages will mess up our prompt and command echo,
            # so we'll need to clear the message buffer and assert an ash prompt again:
            self.ser.reset_input_buffer()
            while self.ser.in_waiting != 0:
                self.readline()
                time.sleep(0.5)

            try:
                self.assert_ash_prompt()
            except AssertionError:
                pass
            return True, message
        return False, message


    def move(self, location):
        if type(location) == list:
            for loc in location:
                self.check_estop(self.write(f"move {loc}\n".encode('latin1')))
        self.check_estop(self.write(f"move {location}\n".encode('latin1')))

    def finish(self, location):
        prompt = self.write(f"move {location}\n".encode('latin1'))
        state, message = self.check_estop(prompt)
        if state:
            return

        #assert prompt.endswith(f"move {location}\r\n".encode('latin1'))
        self.write(b"finish\n")
        prompt = b""
        while prompt.decode('latin1') != f"{PROMPT_TEXT}> ":
            prompt += self.ser.read()
            estop, message = self.check_estop(prompt)
            if estop:
                break
        ArmSerial.logger.info("read()", prompt=prompt)

    def close(self):
        self.ser.close()

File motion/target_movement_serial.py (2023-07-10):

import time

from serial_base import SerialBase


class TargetMovementSerial(SerialBase):
    START_COMMAND = "start"
    STOP_COMMAND = "stop"

    START_SERIAL_COMMAND = b"flail\n"
    STOP_SERIAL_COMMAND = b"stop\n"

    def __init__(self, *args, **kwargs):
        super().__init__(*args, **kwargs)
        self.command = None

    def run(self):
        while not self.stop:
            match self.command:
                case TargetMovementSerial.START_COMMAND:
                    self.write(TargetMovementSerial.START_SERIAL_COMMAND)
                case TargetMovementSerial.STOP_COMMAND:
                    self.write(TargetMovementSerial.STOP_SERIAL_COMMAND)

            self.command = None
            time.sleep(0.05)

        # Go to idle before shutdown
        self.write("stop\n")

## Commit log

2023-05-31 Need to tighten up timeout loop
    [talk_to_bot.py]
2023-06-10 Added schematic for the SysIO breakout box and stack light. It's probably correct.
    [PPPRoboSysIOStackLight.kicad_pcb, PPPRoboSysIOStackLight.kicad_sch]
2023-06-21 WIP but still need to work out threading for flip digits
    [flipdigits.py, mqtt_consumer.py]
2023-07-01 Add scoreboard timer stubs
2023-07-09 Make poll messages fixed length.
    [PPP_IR_RawParse.ino]
2023-07-09 Fix set number flippies
    [mqtt_consumer.py]
2023-07-09 Fix small bug with how clearing works on flip digits
    [mqtt_consumer.py]
2023-07-10 Fix display 0 bug
    [mqtt_consumer.py]
2023-07-10 Fix timer (kinda)
2023-07-10 Set serial start command to the correct value
    [target_movement_serial.py]
2023-07-10 Reset score on game start
    [target_scoring_mqtt_consumer.py]
2023-07-12 Reworked target commands as a queue.
    [target_scoring_mqtt_consumer.py, target_scoring_serial.py]
2023-07-26 Definitely didn't do this all at the convention
    [arm_serial.py, highscores.py, scoreboard.py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]
2024-06-08 Added missing source for target stepper controller.
    [PPP_Stepper_Controller.ino]
2024-06-09 2024 target gantry CAD files
    [ArmTargetGantry.cfg, ArmTargetGantryMain.stl, ArmTargetGantryMain_v2.stl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]
2024-06-10 So many great changes
    * Changed serial device names to use nice symlink names
    * Added parking feature to robot arm motion
    * By the power of bonk, sides fumble no longer
    * Add better estop handling to robot motion
    * Add Ctrl+C handler to main gameplay script as soft estop
    * Disable side target recalibration routine
    * Add dingding systemd handler
    [arm_mqtt_consumer.py, arm_serial.py, target_movement_mqtt_consumer.py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]
2024-06-11 Added missing schematics.
    [PPPRobotTargetTransceiver.kicad_pcb, PPPRobotTargetTransceiver.kicad_sch]
2025-06-19 Implement steppies for targets
    1) Move the existing target controller code to platformio
    2) Implement the home, show, hide commands to allow the controller
    to control a stepper motor attached via an A4498 stepper driver
    3) Update poll to include the state of the stepper motor.
    4) Move the serial processing to non-blocking to reduce
    interrupting ongoing stepper movement.
    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
2025-07-04 Adds support for UP/DOWN/HOME commands for flippy targets
    Adds support for UP/DOWN/HOME commands and adds some logic
    for homing at the start of the game, homing at the end of the game
    and randomly flipping up/down targets during the game.
    Test: wat is that
    [main.cpp, target_blinkies.py, target_blinkies_mqtt_consumer.py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]
2025-07-04 Fixes for target movement
    - only 2 targets are chosen at a time to reduce the current of moving multiple targets
    - the StepperDriver code will now not accept another setPosition command until it
    stops moving to ensure it doesnt move more than 90 degress in any direction
    [main.cpp, target_blinkies.py]
2025-07-09 Disable non-critical stuff during stepper moves
2025-07-12 Remap pins for latest PCB and add support for acceleration/deceleration
2025-07-14 Add ability to flip target dir and implement making target react to getting hit.
    [main.cpp]
2025-07-17 Fixes all manner of things
    [main.cpp, target_blinkies.py, target_blinkies_mqtt_consumer.py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]
2025-07-17 Move delays to non blocking for more stable motor control. Also move to 14400 baud rate
2025-07-18 Hack to fix race condition in blinkies
    [arm_mqtt_consumer.py, target_blinkies.py, target_blinkies_mqtt_consumer.py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]
2026-07-12 Set stance in startup script, add spacer CAD
    [spacer.scad, spacer.stl]
2026-07-12 Fix likely sources of discovery issues
    [main.cpp, target_scoring_serial.py]
2026-07-16 Remove redundant timer for publishing "up" command
